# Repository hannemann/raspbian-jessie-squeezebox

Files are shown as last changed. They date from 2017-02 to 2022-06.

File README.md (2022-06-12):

# raspbian-jessie-squeezebox

### Hardware
* Raspi 3
* Behringer ufo202 (comes with integrated phono preamp and works ootb with raspbian jessie)
* Behringer uca202 (works ootb with raspbian jessie)
* Hifiberry DAC+
* Superpower HTPC Case with integrated 7" Touchscreen and a front Panel with 5 tactile switches, a power switch and a IR receiver (the panel does not work in any way and has to be modified)
For the DAC to work add following line to /boot/config.txt
```
dtoverlay=hifiberry-dacplus
```
I soldered pin headers to the dac. Most GPIO pins can then be used for... general purpose. We use them to read the buttons from the front panel and the ir-receiver. Also the display and PSU can be turned on and off. To make this work i made a pcb from perfboard with some resistors and transistors. Not too hard to build. To connect the PSU i salvaged the atx connector from an outaged motherboard and glued it on the pcb.

### Install and Configure Alsa Equalizer Plugin
```
sudo apt-get install libasound2-plugin-equal
```
Equal related configuration in /etc/asound.conf:
```
ctl.equal {
	type equal;
	controls "/home/pi/.alsaequal.bin"
}
 
pcm.plugequal {
	type equal;
	slave.pcm "sysdefault:CARD=sndrpihifiberry";
	controls "/home/pi/.alsaequal.bin"
}
 
pcm.equal {
	type plug;
	slave.pcm plugequal;
}
```

To adjust sound to your likings type
```
sudo alsamixer -D equal
```
### install squeezelite
```
sudo apt-get install squeezelite
```
Squeezelite can be configured via /etc/default/squeezelite. Since we use the equalizer plugin for alsa the soundcard has to be set
* [/etc/default/squeezelite line 11](https://github.com/hannemann/raspbian-jessie-squeezebox/blob/master/etc/default/squeezelite#L11)
You can also set an arbitrary name if you like

### Jivelite
dependencies installed:
* git
* libsdl1.2-dev
* libsdl-ttf2.0-dev
* libsdl-image1.2-dev
* libsdl-gfx1.2-dev
* libexpat1-dev

dependencies compiled:
* luajit
```
git clone http://luajit.org/git/luajit-2.0.git
cd luajit-2.0
make
sudo make install
cd ..
```

### Compile Jivelite
```
git clone https://code.google.com/p/jivelite/
cd jivelite
sudo make
```
These commands create a binary in the bin subfolder that can be executed from a terminal on the display you want to use it. Starting the binary via ssh does not work.

### Autologin via systemd and start jivelite
* create [/etc/systemd/system/getty-tty1.service.d/override.conf](https://github.com/hannemann/raspbian-jessie-squeezebox/blob/master/etc/systemd/system/getty-tty1.service.d/override.conf)
* create [/home/pi/.bash_profile](https://github.com/hannemann/raspbian-jessie-squeezebox/blob/master/home/pi/.bash_profile)

## Hardware
ATX Power supply for the PI via +5VSB and switching the PSU on already working. More to come...
### ATX Power Supply for the PI
Cut an old USB cable and connect the red wire with the purple wire of the ATX PSU and the black wire with any of the black wires of teh ATX PSU.
### Switching the psu
To switch the PSU on via GPIO pin i connected the green and a black wire of the PSU with the emitter and collector of an NPN transistor. The base connects to an 10K Resistor and that to an GPIO Pin. If i set the GPIO to high, the PSU switches on.

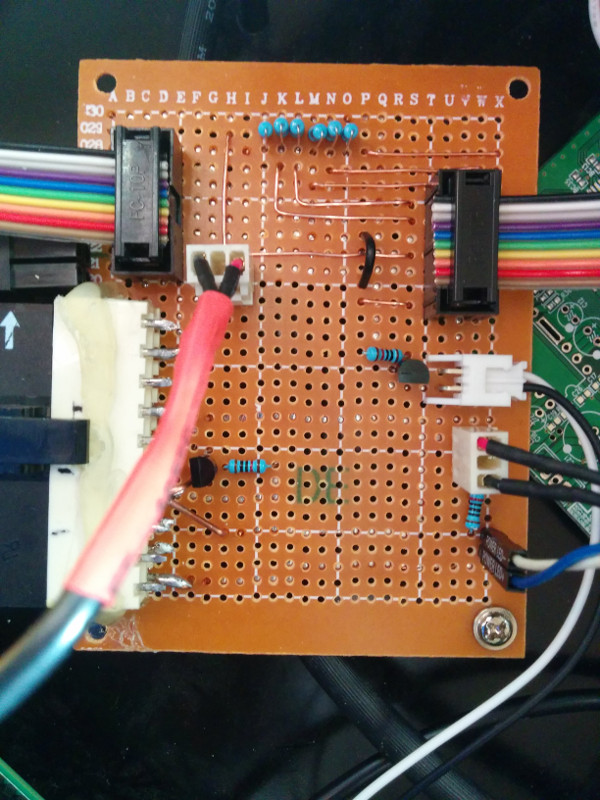
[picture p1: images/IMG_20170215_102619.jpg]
perfboard


### Hardware for lirc via GPIO
I have used a TSOP4838 IR Receiver. The pinout can be found in several Datasheets available around the internet.

Connect pin VCC to a +3.3V pin of the PI, pin GND to a ground pin and the data pin to an arbitrary GPIO pin e.g. Pin 22 (BCM).

Edit /boot/config.txt:
```
dtoverlay=lirc-rpi,gpio_in_pin=22,gpio_out_pin=27
```

### Install and configure lirc
```
sudo apt-get install lirc
```
[hardware.conf](https://github.com/hannemann/raspbian-jessie-squeezebox/blob/master/etc/lirc/hardware.conf)
```
irrecord -n -d /dev/lirc0 remote # follow instructions
sudo cp remote /etc/lirc/lircd.conf
```
### Tactile Switches of the HTPC case
the GPIOs i use are pulled to high via an 10K Resistor connected to +3.3V Pin. The switches connect to the GPIOs and to Ground. If i press a switch the GPIO falls which can easily detected with the wiringpi library.
```
sudo apt-get install wiringpi
```
To see how this works have a look at [/home/pi/bin/panel-lib](https://github.com/hannemann/raspbian-jessie-squeezebox/blob/master/home/pi/bin/panel-lib)

Next steps: the case i am using has some tactile switches that can be used for navigation, cd playback via cdrom, eGalax Touchscreen driver and calibration

### Playback from Turntable and AUX Device e.g. Tape
To have lossless streams we use liquidsoap to encode the data from the soundcards to flac piping it to icecast2

#### Install Liquidsoap and Icecast2
```
sudo apt-get install liquidsoap liquidsoap-plugins-all icecast2
```
#### Configure Liquidsoap and Icecast
Create *.liq files for every source you want to stream
* [aux.liq](https://github.com/hannemann/raspbian-jessie-squeezebox/blob/master/etc/liquidsoap/aux.liq)
* [phono.liq](https://github.com/hannemann/raspbian-jessie-squeezebox/blob/master/etc/liquidsoap/phono.liq)

Icecast will ask for hostname and passwords while installing. Type in localhost and your password used in darkice configuration. Always use extreme secure passwords!

## Visualization
### VU Meter
#### Squeezelite Configuration
```
sudo vi /etc/default/squeezelite
```
add `-v` parameter to `SB_EXTRA_ARGS="-v"`  
#### To change the VU Meter edit:
```
vi ~/jivelite/share/jive/applets/JogglerSkin/JogglerSkinApplet.lua
```
Find `vumeter_analog` and change the path to image accordingly.  
You can find images in:
```
ls -l ~/jivelite/share/jive/applets/JogglerSkin/images/UNOFFICIAL/VUMeter/
```
`killall jivelite` will restart it.

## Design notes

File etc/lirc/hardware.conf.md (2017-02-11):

### Lirc hardware.conf
```
# /etc/lirc/hardware.conf
#
# Arguments which will be used when launching lircd
LIRCD_ARGS="--uinput"

#Don't start lircmd even if there seems to be a good config file
#START_LIRCMD=false

#Don't start irexec, even if a good config file seems to exist.
START_IREXEC=true

#Try to load appropriate kernel modules
LOAD_MODULES=true

# Run "lircd --driver=help" for a list of supported drivers.
DRIVER="default"
# usually /dev/lirc0 is the correct setting for systems using udev
DEVICE="/dev/lirc0"
MODULES="lirc_rpi"

# Default configuration files for your hardware if any
LIRCD_CONF=""
LIRCMD_CONF=""
```

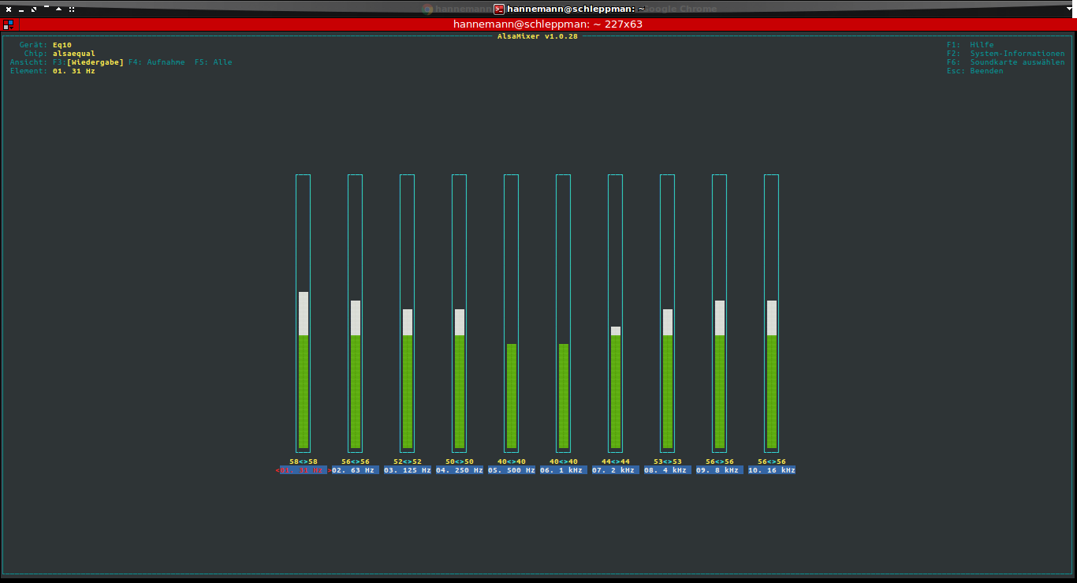
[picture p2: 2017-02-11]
equalizer-settings.png

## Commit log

2017-02-19 Add schematics
    [Squeezebox.fzz]
2017-02-19 add display switch header to schematic
    [Squeezebox.fzz]
2017-02-19 Breadboard optimization
    [Squeezebox.fzz]
2022-09-30 fix socket recv
